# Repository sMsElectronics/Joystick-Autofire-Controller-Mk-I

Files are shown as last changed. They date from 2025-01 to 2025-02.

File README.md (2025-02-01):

# Joystick Auto Fire Controller V1.1
 ### This is a small form factor digitally controlled auto fire PCB with 0.1" connector headers for convenient installation into Commodore 64 and Atari Joysticks. It can be used to create custom DIY joysticks. Fire rates can be controlled using a potentiometer (analog mode) to smoothly transition from fire rate from 2 to 25 pulses per second (PPS). Alternatively, you can enter a fixed rates mode (digital Mode) with a series of button presses. The fixed rate selections are 5, 10, and 15 PPS. A normal mode is also possible by disabling the auto fire in both scenarios above. All feedback is displayed on an RGB WS2812B compatible LED and FIRE LED. Various colors and fade animation are displayed representing all the modes and rates. Further below, these modes and how to enter them are described in the illustrations

 ## *The complete and tested auto fire controller PCB's, complete with documentation, are available on my sMs Retro Electronics KoFi Shop*

## [sMs Retro Electronics KoFi Shop](https://ko-fi.com/smsretroelectronics)

 ## Size of board compared to the end of a pen.  

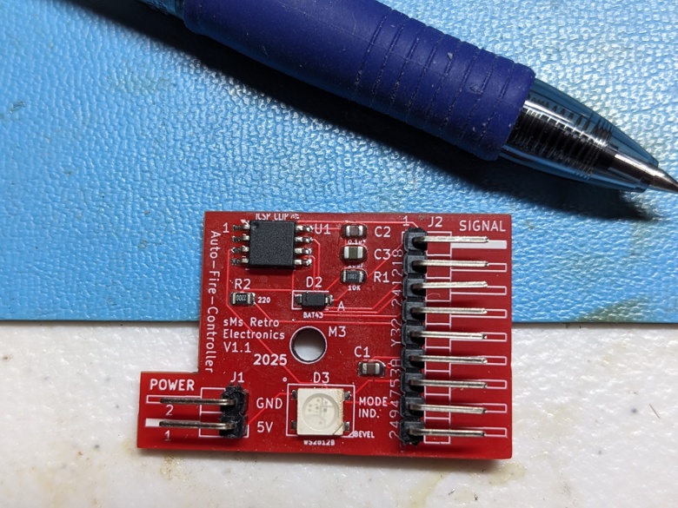
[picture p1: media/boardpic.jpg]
 

 ## PCB TOP VIEW
 
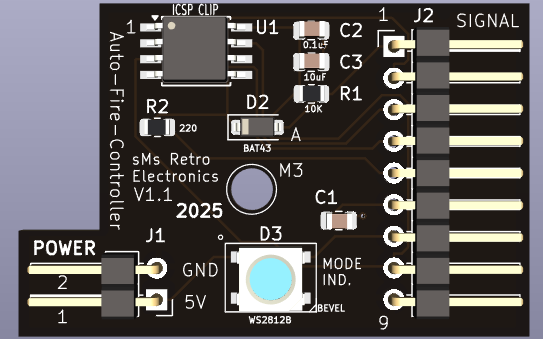
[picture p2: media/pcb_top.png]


 ## PCB BOTTOM VIEW
### A convenient silkscreen showing signal names NOTE: SQUARE PIN = 1

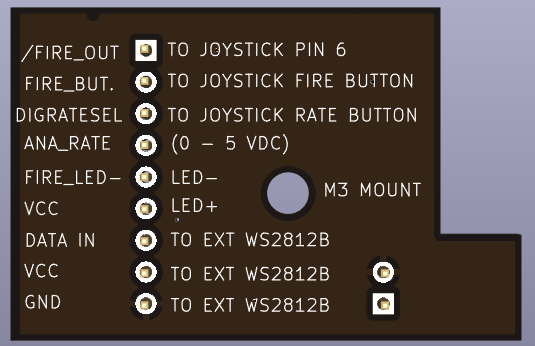
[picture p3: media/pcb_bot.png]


# J2 Signal Definitions: 

|Pin Number|Signal Name|Description|
|:--:|:--:|:--|
|1|/FIRE OUT|Active low signal output that emulates the trigger into the C64 or other computer to auto fire a weapon. This signal is normally HIGH. Signal wires to pin 6 of a joystick: 
|2|FIRE_BUT|Signal from fire control button on joystick. This signal pulls LOW each time the joystick fire button is pressed. This signal is normally HIGH. :
|3|DIGRATESEL|Selects the auto fire rate. Rates of 5, 10 and 20 PPS are selectable. A Quick press cycles theSE rates. A long press FOR 1.5+ seconds enables the analog rate control| 
|4|ANA_RATE|A 0-5 VDC input from external 10K potentiometer to vary the fire rate from 2 to 23 pulses per second. This potentiometer input is only active if the joystick is set to smooth analog fire control|
|5|Fire LED-|output for user option to mount external led to indicate the press of the fire button in normal mode or to indicate auto fire pulsing in either of two auto fire modes|
|6|VCC|supply for LED+. No limiting resistor is required|
|7|DATA IN|External Neopixel RGB LED Data IN Signal|
|8|VCC|5V supply for Neopixel|
|9|GND|Ground connection for Neopixel|

# J1 Signal Definitions: 

|Pin Number|Signal Name|
|:--:|:--|
|1|5V IN|
|2|GROUND| 
   
# Summary of Modes

- Fixed Auto fire Mode
- Smooth or Analog Fire 
- Normal Mode
  
# How to Enter and Operate Each Mode

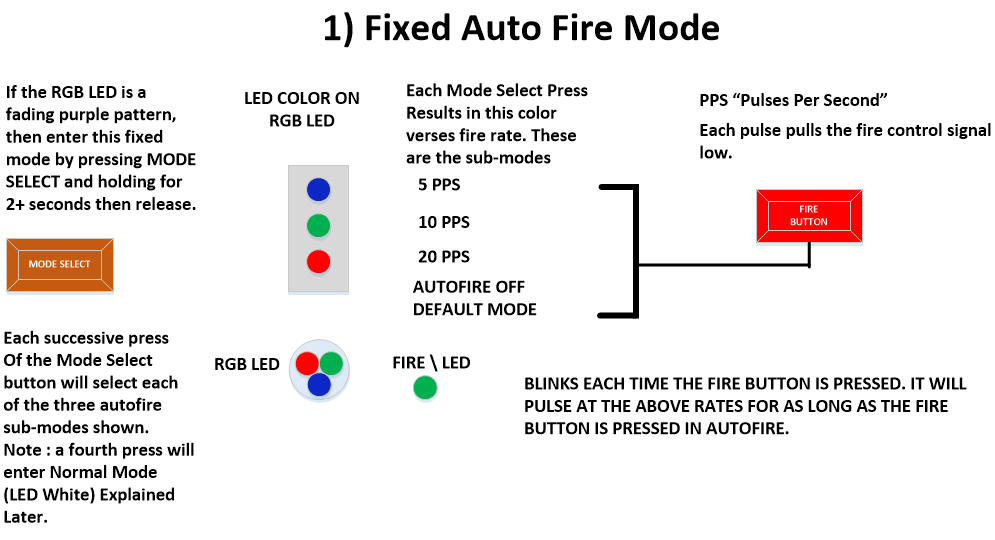
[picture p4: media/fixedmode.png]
 
 <BR>

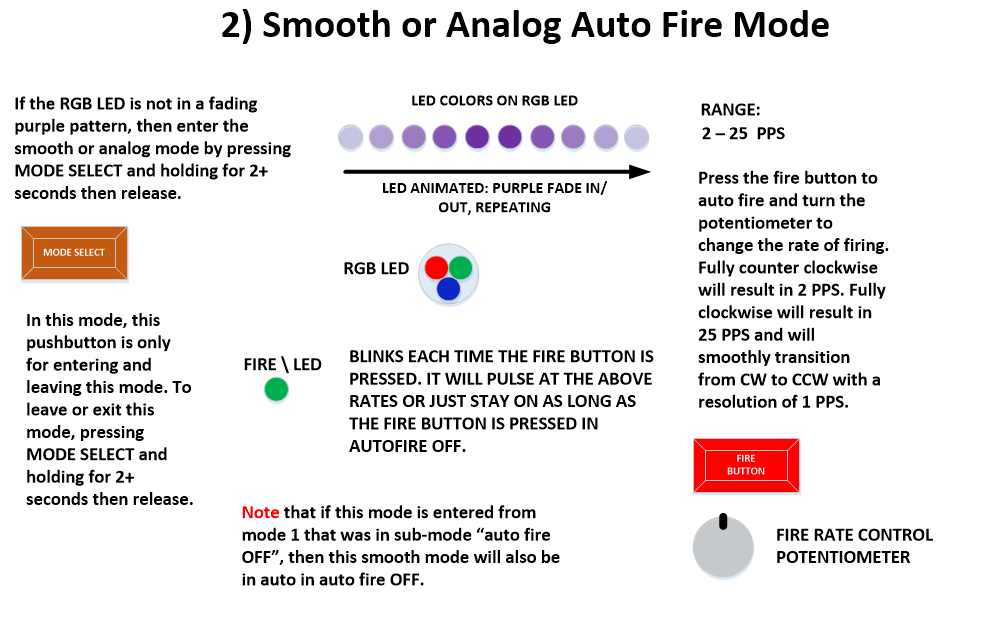
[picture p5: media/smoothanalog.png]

<BR>

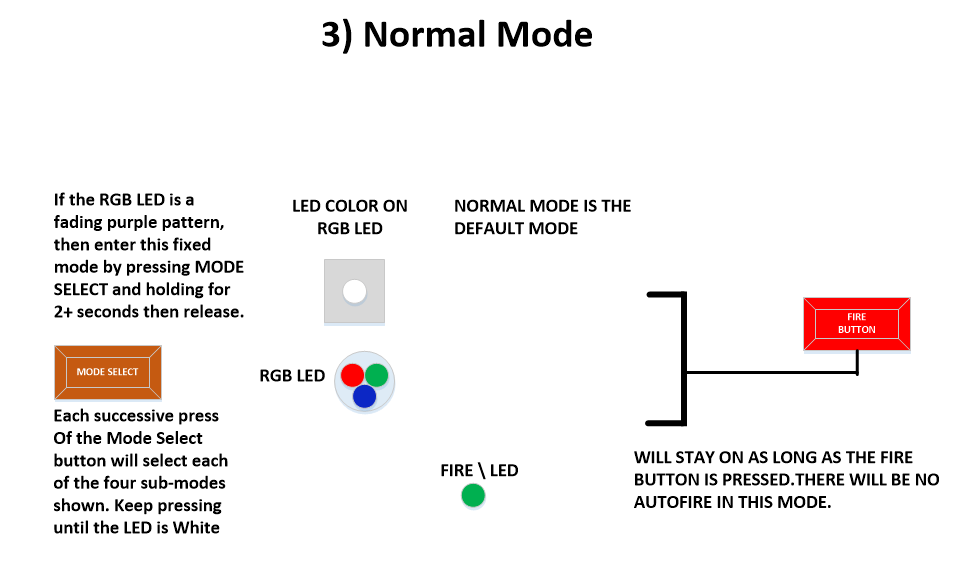
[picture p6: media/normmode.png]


# Typical application in a joystick design

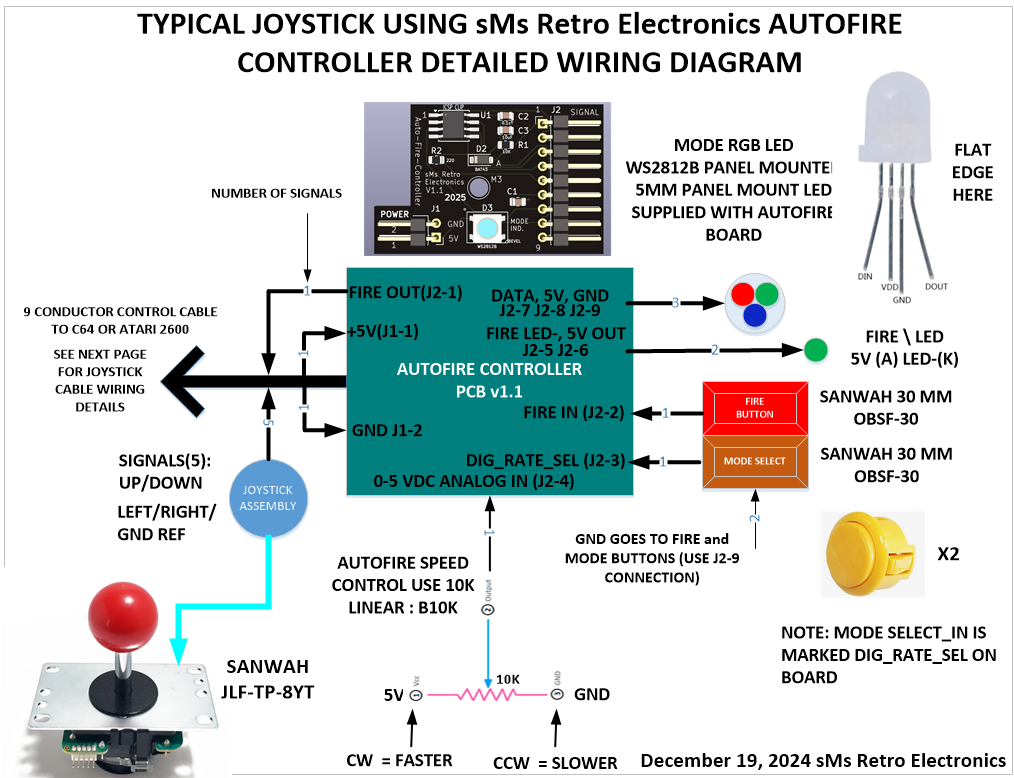
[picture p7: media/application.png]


# Joystick wiring details

The following diagram shows how to wire a Sanwah JLF-TP-8YT joystick , or compatible, assembly to a 9 PIN joystick cable. Some cables may be different in their color coding so its best to check continuity from each pin to the wires and identify the color verses pin. 

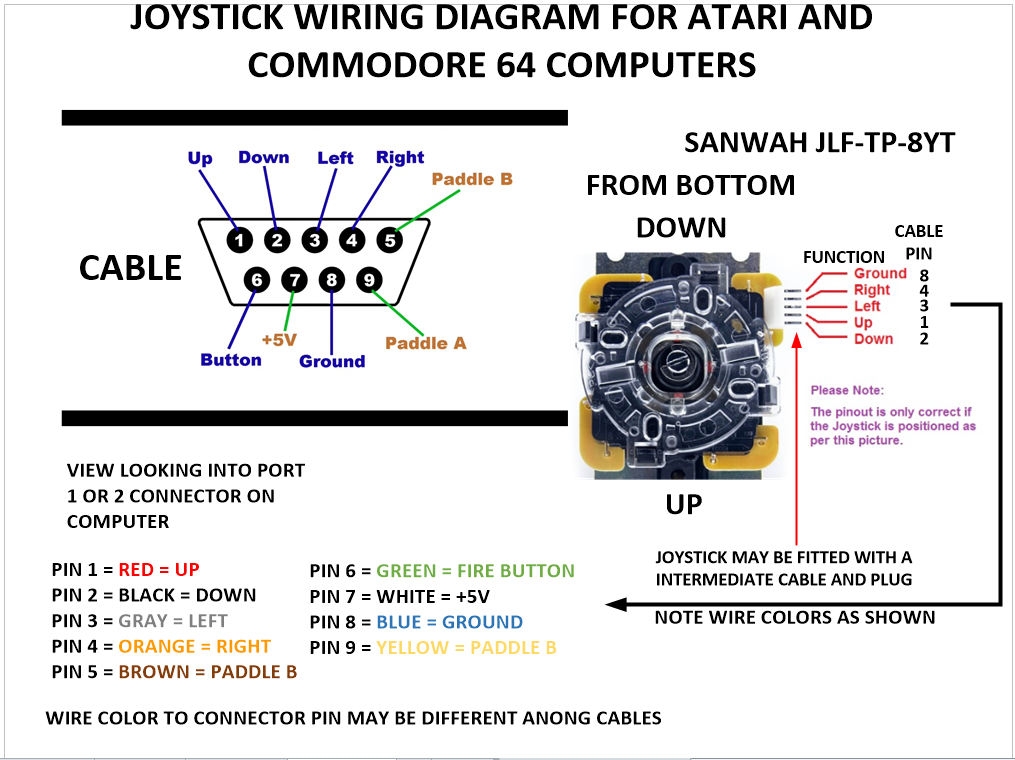
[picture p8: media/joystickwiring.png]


## If you want to DIY build your boards, the source files are available in the VS Code folder. Just keep in mind that when you create the project, inside the "libdeps" folder that contains the Tinbutton folder and TinyButton.cpp file. This file has been modifed to work with this project with the following changes. It was found that a long button press of 4 seconds was way too long and the long press woul dbe activated in 1.5 seconds instead.    

   ## Modification to file ***TinyButton.cpp*** to Shorten the LONG press criteria from 4 seconds to 1.5 seconds 
   ### W.Manganaro 2025
   
## FROM:    

      if ((currentMillis - _buttonPressTime) >= 4000)  
## TO:    

      //Value changed from 4000 to 1500 to validate a LONG press in a shorter time (approx 1.5 seconds)
      if ((currentMillis - _buttonPressTime) >= 1500)

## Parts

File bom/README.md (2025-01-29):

| Reference | Value | Footprint | Qty |
|---|---|---|-----|
| C1,C2,C3  | 0.1uF_0805_16V | Capacitor_SMD:C_0805_2012Metric | 3 |
| D2 | BAT43 | Diode_SMD:D_SOD-123 | 1 |
| D3 | WS2812B | LED_SMD:LED_WS2812B_PLCC4_5.0x5.0mm_P3.2mm | 1 |
| J1 | Conn_01x02 | Connector_PinHeader_2.54mm:PinHeader_1x02_P2.54mm_Horizontal | 1 |
| J2 | Conn_01x09 | Connector_PinHeader_2.54mm:PinHeader_1x09_P2.54mm_Horizontal | 1 |
| R1 | 10k_0805 | Resistor_SMD:R_0805_2012Metric | 1 |
| R2 | 220_0805 | Resistor_SMD:R_0805_2012Metric | 1 |
| U1 | ATtiny85V-10SU | Package_SO:SOIC-8W_5.3x5.3mm_P1.27mm | 1 |

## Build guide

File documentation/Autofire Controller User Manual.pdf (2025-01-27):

# AUTOFIRE CONTROLLER ASSEMBLY

# TOP

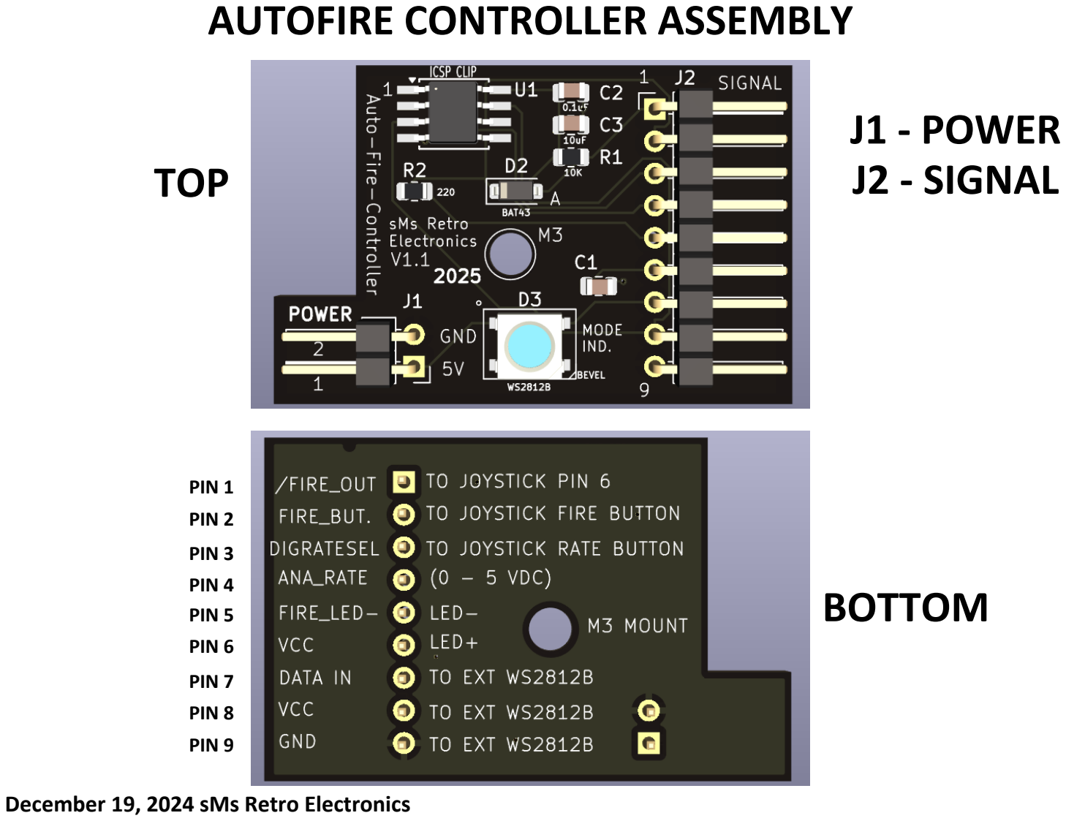
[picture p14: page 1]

# BOTTOM

# J1 - POWER J2 - SIGNAL

PIN 1
PIN 2
PIN 3
PIN 4
PIN 5
PIN 6
PIN 7
PIN 8
PIN 9

December 19, 2024 sMs Retro Electronics

# AUTOFIRE CONTROLLER SCHEMATIC DIAGRAM

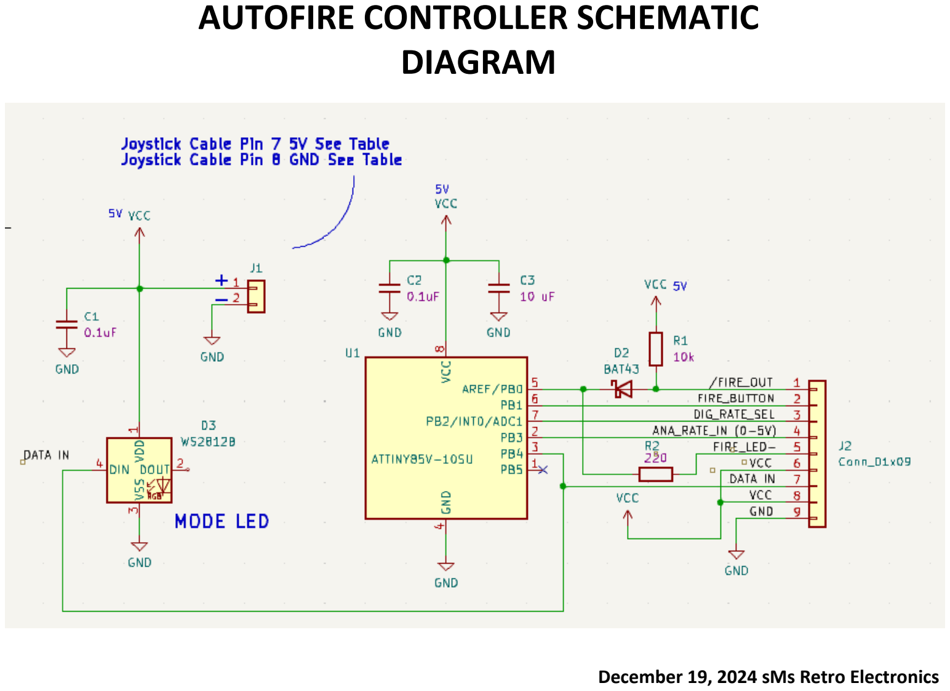
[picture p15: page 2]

# AUTOFIRE CONTROLLER SIGNAL DESCRIPTIONS

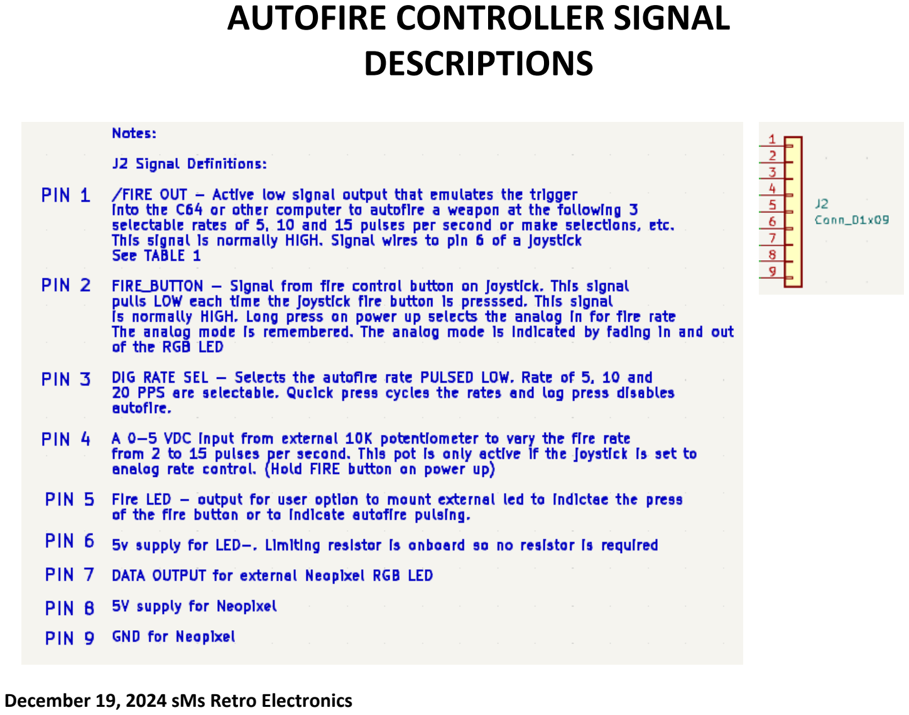
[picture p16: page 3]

### Three Modes of Operation. (Modes 1 & 2 Press and Hold Fire Button) 1) Fixed Auto Fire

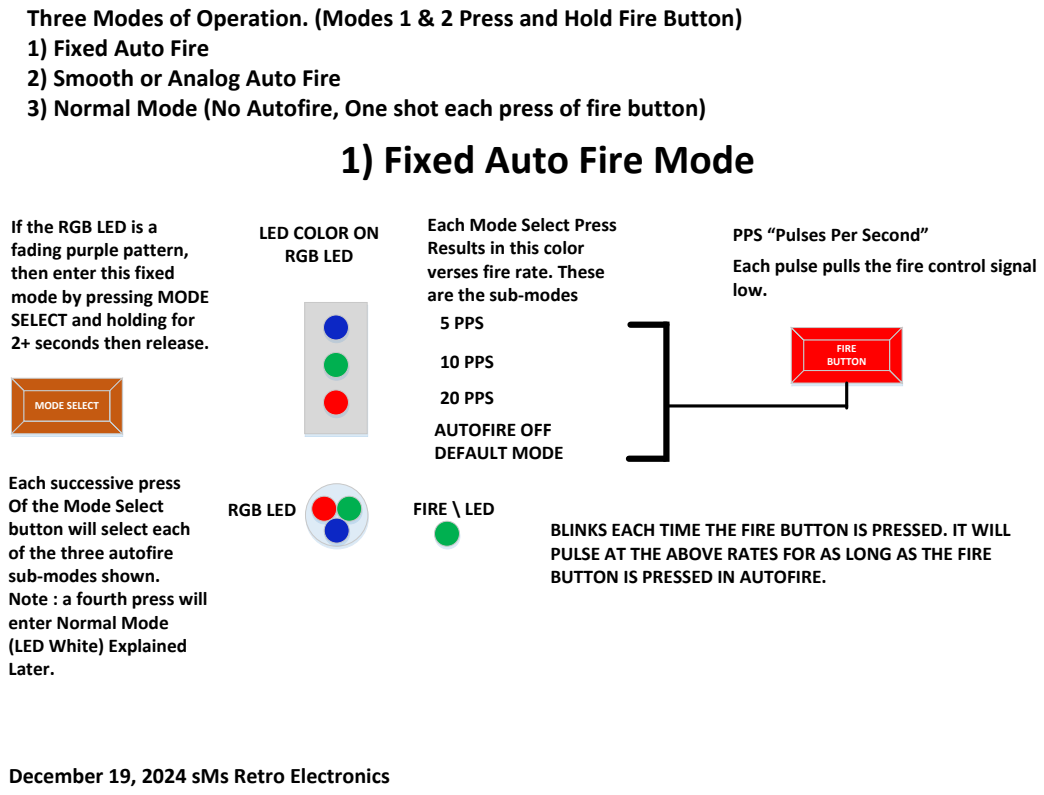
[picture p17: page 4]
10 PPS; 20 PPS; AUTOFIRE OFF DEFAULT MODE; low.; Button FIRE BUTTON; MOBDuEtStoEnLECT; RGB LED

2) Smooth or Analog Auto Fire
3) Normal Mode (No Autofire, One shot each press of fire button)

1) Fixed Auto Fire Mode

If the RGB LED is a
fading purple pattern, then enter this fixed

LED COLOR ON
RGB LED

Each Mode Select Press
Results in this color
verses fire rate. These
are the sub-modes
5 PPS

PPS “Pulses Per Second” Each pulse pulls the fire control signal

mode by pressing MODE
SELECT and holding for
2+ seconds then release.

Each successive press
Of the Mode Select
button will select each
of the three autofire
sub-modes shown. Note : a fourth press will

BUTTON IS PRESSED IN AUTOFIRE. FIRE \ LED

BLINKS EACH TIME THE FIRE BUTTON IS PRESSED. IT WILL
PULSE AT THE ABOVE RATES FOR AS LONG AS THE FIRE

enter Normal Mode
(LED White) Explained
Later.

FIRE RATE CONTROL
POTENTIOMETER

2 – 25 PPS

RANGE:

# 2) Smooth or Analog Auto Fire Mode

BLINKS EACH TIME THE FIRE BUTTON IS PRESSED. IT WILL PULSE AT THE ABOVE RATES OR JUST STAY ON AS LONG AS THE FIRE BUTTON IS PRESSED IN

AUTOFIRE OFF. FIRE \ LED

In this mode, this
pushbutton is only
for entering and
leaving this mode. To
leave or exit this
mode, pressing
MODE SELECT and
holding for 2+
seconds then release.

MOBDuEtStoEnLECT

If the RGB LED is not in a fading purple pattern, then enter the
smooth or analog mode by pressing
MODE SELECT and holding for 2+
seconds then release. | RGB LED

Button FIRE
BUTTON

Press the fire button to
auto fire and turn the
potentiometer to
change the rate of firing. Fully counter clockwise

will result in 2 PPS. Fully clockwise will result in

### 25 PPS and will

smoothly transition
from CW to CCW with a
resolution of 1 PPS.

LED COLORS ON RGB LED

LED ANIMATED: PURPLE FADE IN/ OUT, REPEATING

Note that if this mode is entered from mode 1 that was in sub-mode “auto fire OFF”, then this smooth mode will also be in auto in auto fire OFF.

# 3) Normal Mode

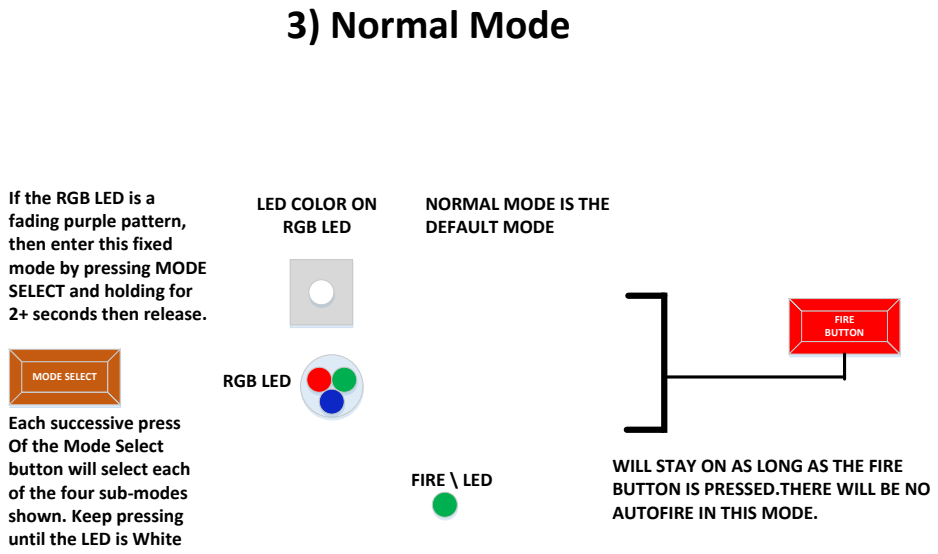
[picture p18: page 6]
Button FIRE BUTTON; MOBDuEtStoEnLECT; RGB LED

If the RGB LED is a
fading purple pattern, then enter this fixed

LED COLOR ON
RGB LED

NORMAL MODE IS THE
DEFAULT MODE

mode by pressing MODE
SELECT and holding for
2+ seconds then release.

Each successive press
Of the Mode Select
button will select each
of the four sub-modes
shown. Keep pressing
until the LED is White

WILL STAY ON AS LONG AS THE FIRE
BUTTON IS PRESSED.THERE WILL BE NO

AUTOFIRE IN THIS MODE. FIRE \ LED

# TYPICAL JOYSTICK USING sMs Retro Electronics AUTOFIRE CONTROLLER DETAILED WIRING DIAGRAM

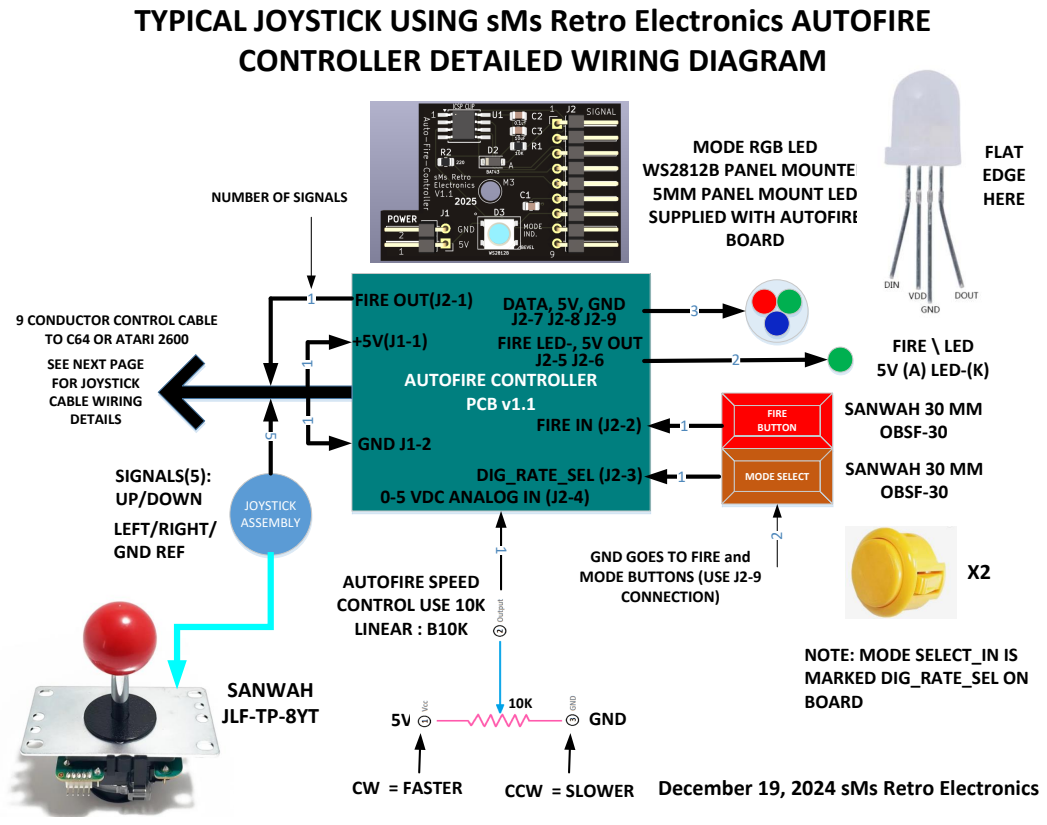
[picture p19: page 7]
AUTOFIRE CONTROLLER PCB v1.1; Button FIRE BUTTON; MOBDuEtStoEnLECT; BOARD; FIRE \ LED 5V (A) LED-(K); FIRE OUT(J2-1); SIGNALS(5): UP/DOWN; LEFT/RIGHT/ GND REF; FIRE IN (J2-2); DIG_RATE_SEL (J2-3); FIRE LED-, 5V OUT; JOYSTICK ASSEMBLY; +5V(J1-1) GND J1-2 ¹ ¹; DATA, 5V, GND; SANWAH 30 MM OBSF-30; FLAT EDGE HERE; AUTOFIRE SPEED CONTROL USE 10K LINEAR : B10K; GND; SANWAH JLF-TP-8YT; CW = FASTER; CCW = SLOWER

MODE RGB LED
WS2812B PANEL MOUNTED
5MM PANEL MOUNT LED
SUPPLIED WITH AUTOFIRE

NUMBER OF SIGNALS

9 CONDUCTOR CONTROL CABLE
TO C64 OR ATARI 2600
SEE NEXT PAGE
FOR JOYSTICK
CABLE WIRING
DETAILS

0-5 VDC ANALOG IN (J2-4)

GND GOES TO FIRE and
MODE BUTTONS (USE J2-9
CONNECTION)

NOTE: MODE SELECT_IN IS
MARKED DIG_RATE_SEL ON
BOARD

# JOYSTICK WIRING DIAGRAM FOR ATARI AND COMMODORE 64 COMPUTERS

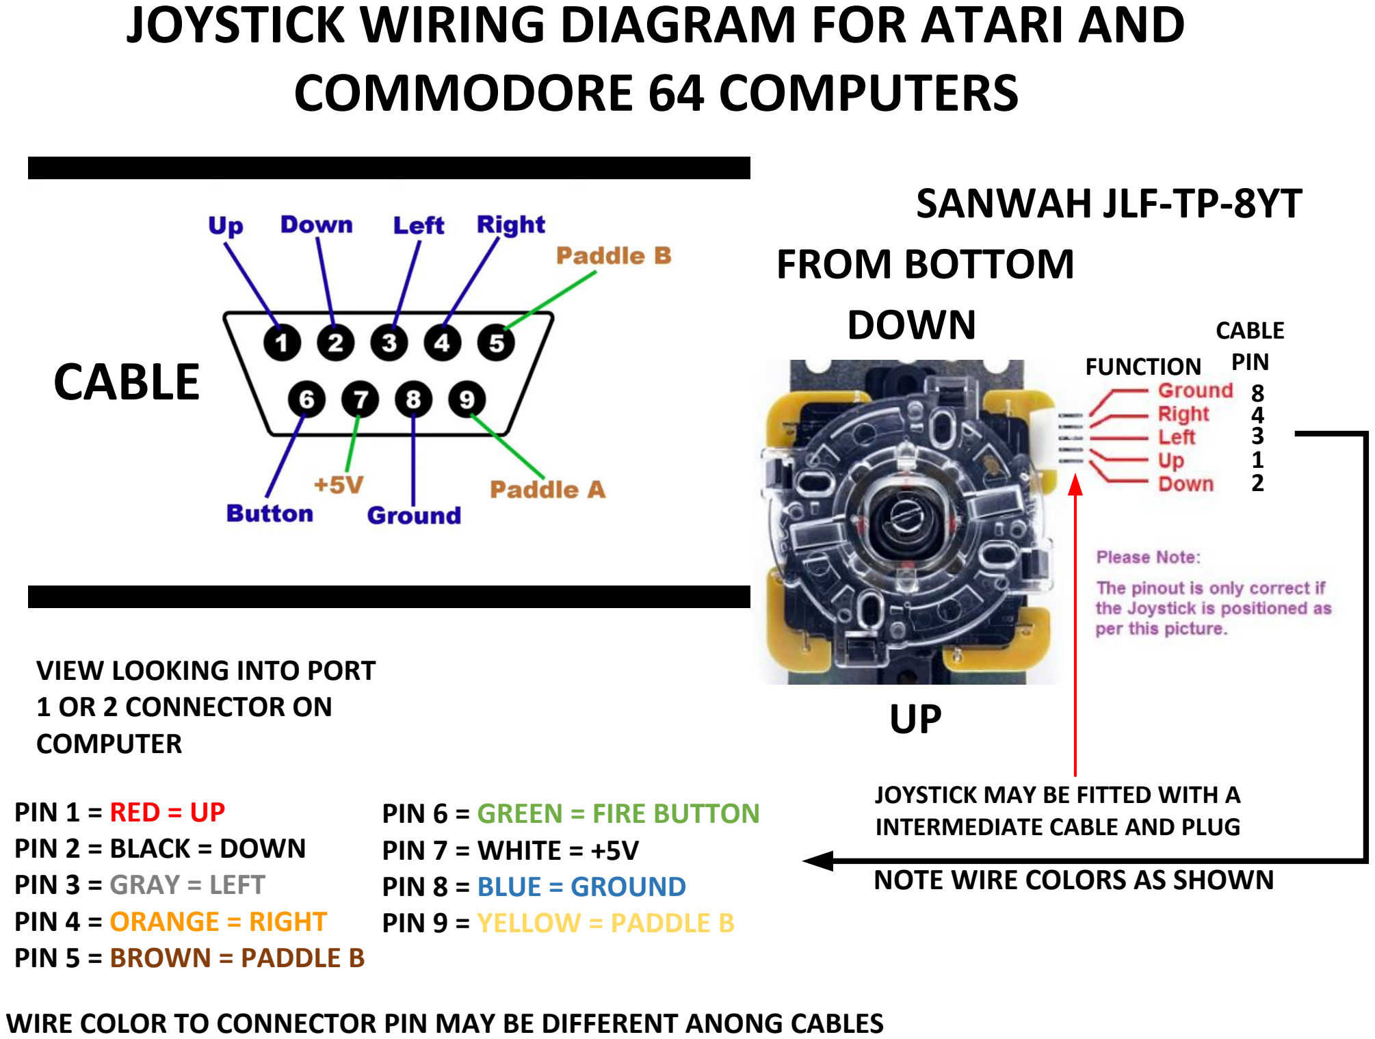
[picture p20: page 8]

VIEW LOOKING INTO PORT

### 1 OR 2 CONNECTOR ON

COMPUTER

PIN 1 = RED = UP
PIN 2 = BLACK = DOWN
PIN 3 = GRAY = LEFT
PIN 4 = ORANGE = RIGHT
PIN 5 = BROWN = PADDLE B

PIN 6 = GREEN = FIRE BUTTON PIN 7 = WHITE = +5V
PIN 8 = BLUE = GROUND
PIN 9 = YELLOW = PADDLE B

WIRE COLOR TO CONNECTOR PIN MAY BE DIFFERENT ANONG CABLES

UP

# DOWN

8
4
3
1
2

CABLE
FUNCTION PIN

JOYSTICK MAY BE FITTED WITH A INTERMEDIATE CABLE AND PLUG

# SANWAH JLF-TP-8YT

# CABLE

# FROM BOTTOM

NOTE WIRE COLORS AS SHOWN

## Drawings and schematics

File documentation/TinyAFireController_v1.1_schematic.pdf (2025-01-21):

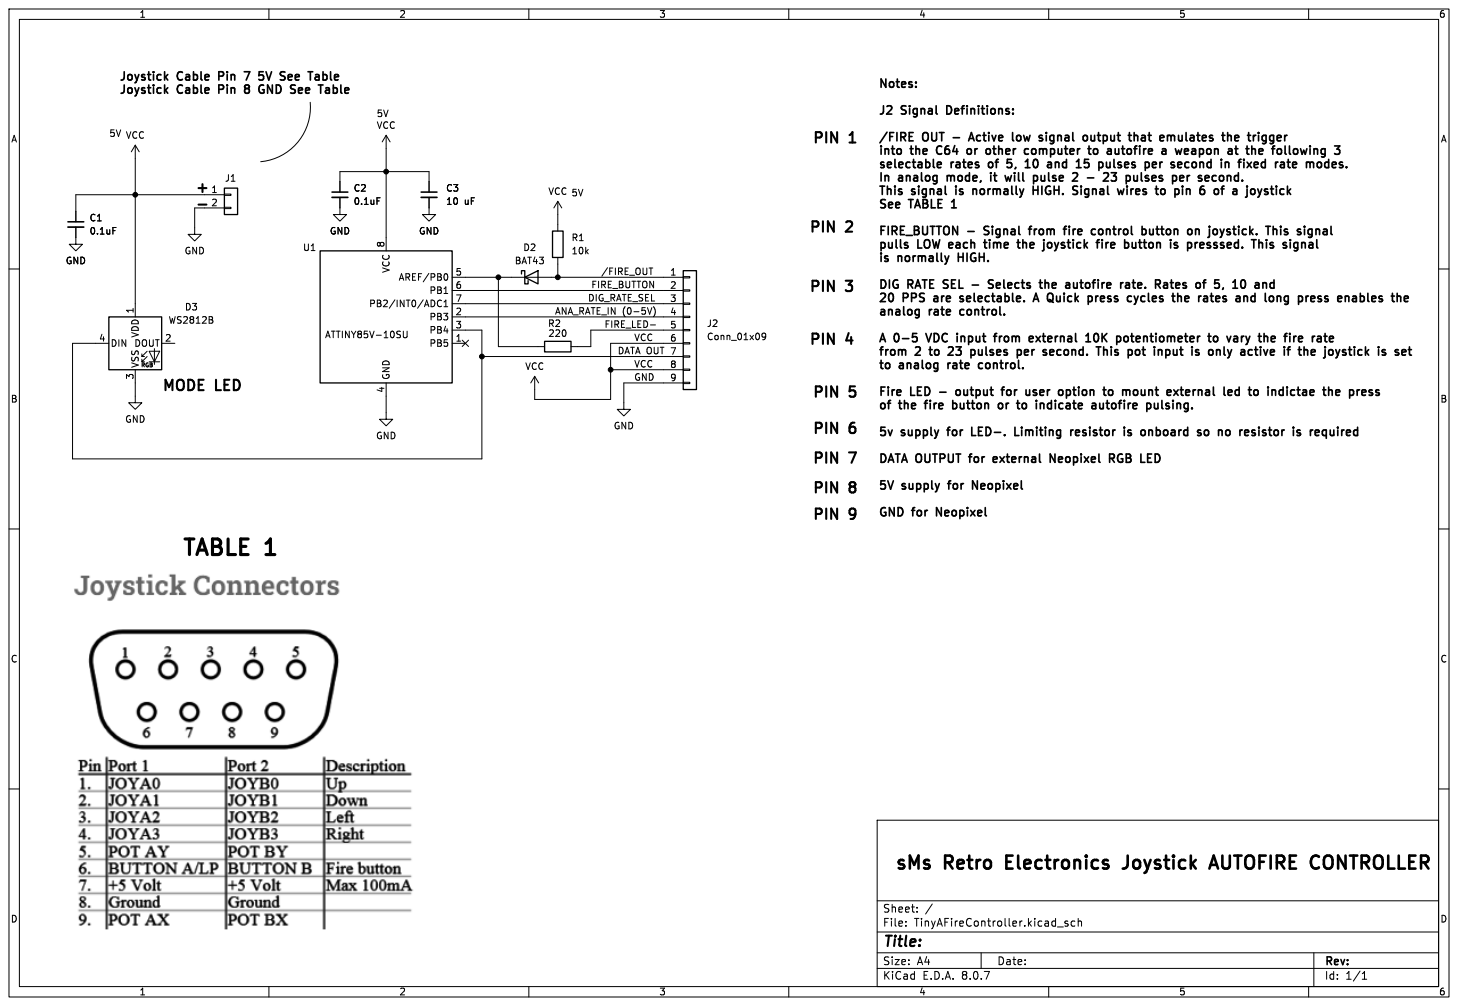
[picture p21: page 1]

Joystick Cable Pin 7 5V See Table
5VJoystick Cable Pin 8 GND See Table

See TABLE 1 FIRE_BUTTON - Signal from fire control button on joystick. This signal

pulls LOW each time the joystick fire button is presssed. This signal
is normally HIGH.

DIG RATE SEL - Selects the autofire rate. Rates of 5, 10 and
analog rate control.

from 2 to 23 pulses per second. This pot input is only active if the joystick is set
to analog rate control.

Fire LED - output for user option to mount external led to indictae the press
of the fire button or to indicate autofire pulsing.

5v supply for LED-. Limiting resistor is onboard so no resistor is required

DATA OUTPUT for external Neopixel RGB LED

Id: 1/1 Title: File: TinyAFireController.kicad_sch Sheet: /

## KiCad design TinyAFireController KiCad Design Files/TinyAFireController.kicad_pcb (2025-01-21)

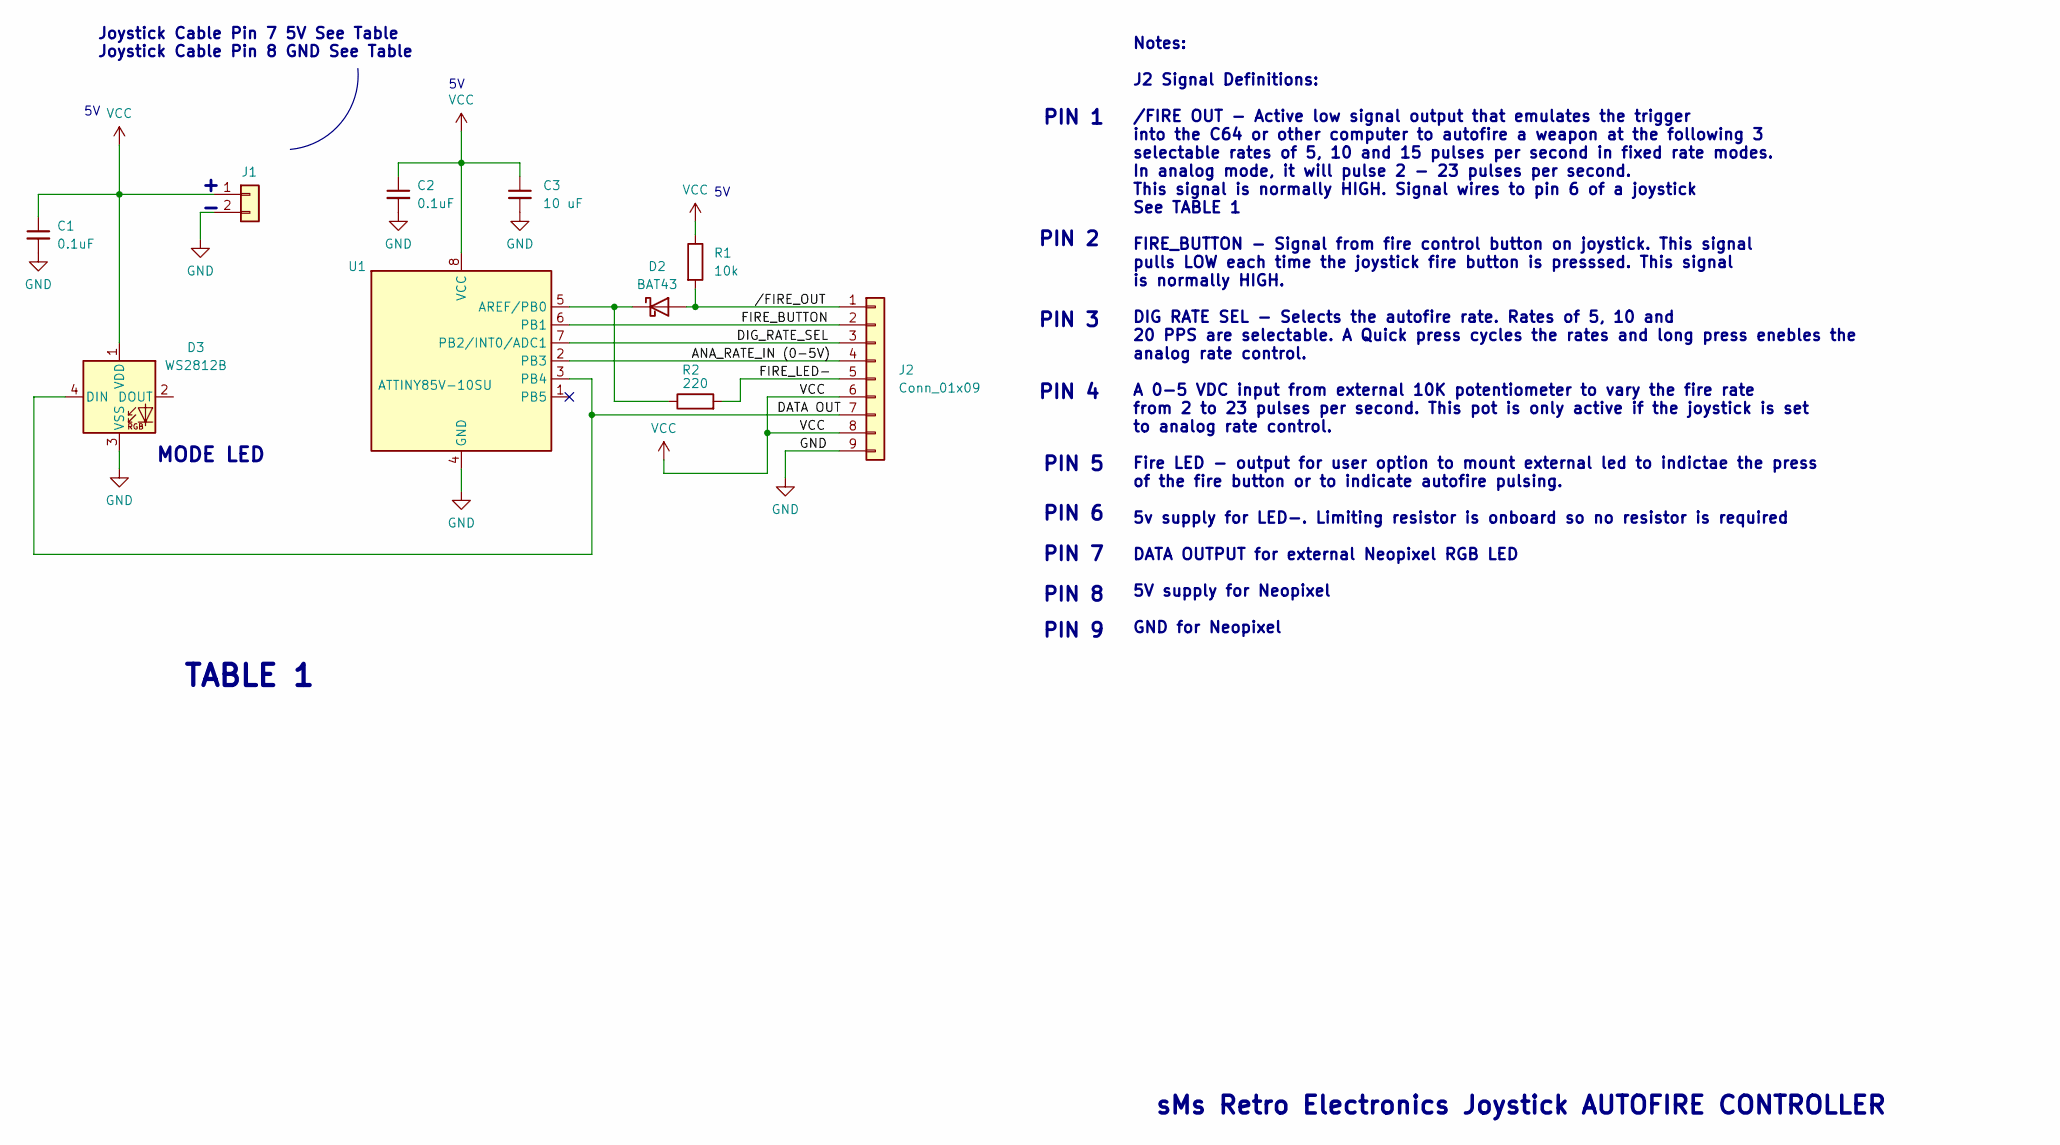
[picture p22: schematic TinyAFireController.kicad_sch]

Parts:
C1, C2, C3: 0.1uF_0603_16V; C_0805_2012Metric; Part Number 0603YC104KAT2A; JLCPCB ID C14663
D2: BAT43; D_SOD-123
D3: WS2812B; LED_WS2812B_PLCC4_5.0x5.0mm_P3.2mm
J1: Conn_01x02; PinHeader_1x02_P2.54mm_Horizontal; Part Number 1-0201FBV0T
J2: Conn_01x09; PinHeader_1x09_P2.54mm_Horizontal; Part Number 1-0901FBV0T
R1, R2: 100k_0603; R_0805_2012Metric; Part Number RC0603FR-07100KL; JLCPCB ID C25803
U1: ATTINY85V-10SU; SOIC-8W_5.3x5.3mm_P1.27mm

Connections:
/: D2.1 (K), R2.1, U1.5 (AREF/PB0)
/ANA_RATE_IN (0-5V): J2.4, U1.2 (PB3)
/DATA IN: D3.4 (DIN), J2.7, U1.3 (PB4)
/DIG_RATE_SEL: J2.3, U1.7 (PB2/INT0/ADC1)
/FIRE_BUTTON: J2.2, U1.6 (PB1)
/FIRE_LED-: J2.5, R2.2
//FIRE_OUT: D2.2 (A), J2.1, R1.2
GND: C1.2, C2.2, C3.2, D3.3 (VSS), J1.2, J2.9, U1.4 (GND)
VCC: C1.1, C2.1, C3.1, D3.1 (VDD), J1.1, J2.6, J2.8, R1.1, U1.8 (VCC)

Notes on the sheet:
TABLE 1
PIN 5
Joystick Cable Pin 7 5V See Table
PIN 7
PIN 1
PIN 3
PIN 6
sMs Retro Electronics Joystick AUTOFIRE CONTROLLER
MODE LED
PIN 8
Notes: J2 Signal Definitions: /FIRE OUT - Active low signal output that emulates the trigger into the C64 or other computer to autofire a weapon at the following 3 selectable rates of 5, 10 and 15 pulses per second in fixed rate modes. In analog mode, it will pulse 2 - 23 pulses per second. This si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
Joystick Cable Pin 8 GND See Table
PIN 4
PIN 2
PIN 9

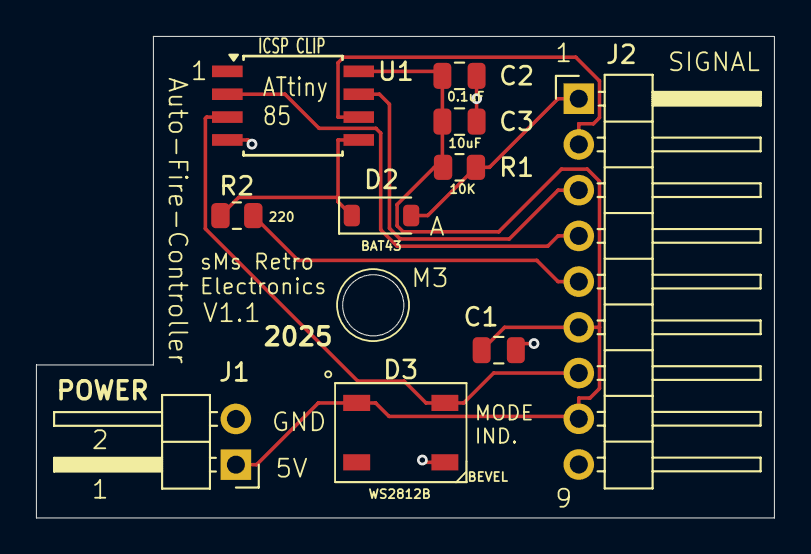
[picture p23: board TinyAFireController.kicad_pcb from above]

Board: 2 copper layers, 41.0 x 26.8 mm, 10 parts (0 on the bottom side), 9 nets.

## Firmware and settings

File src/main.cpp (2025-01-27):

/*  ; MIT License
; 
; Copyright (c) 2025 William Manganaro sMs Retro Electronics
; 
; Permission is hereby granted, free of charge, to any person obtaining a copy of this software 
; and associated documentation files (the "Software"), to deal in the Software without 
; restriction, including without limitation the rights to use, copy, modify, merge, publish, 
; distribute, sublicense, and/or sell copies of the Software, and to permit persons to whom 
; the Software is furnished to do so, subject to the following conditions:
; 
; The above copyright notice and this permission notice shall be included in all copies or 
; substantial portions of the Software.
; 
; THE SOFTWARE IS PROVIDED "AS IS", WITHOUT WARRANTY OF ANY KIND, EXPRESS OR IMPLIED, INCLUDING 
; BUT NOT LIMITED TO THE WARRANTIES OF MERCHANTABILITY, FITNESS FOR A PARTICULAR PURPOSE AND 
; NONINFRINGEMENT. IN NO EVENT SHALL THE AUTHORS OR COPYRIGHT HOLDERS BE LIABLE FOR ANY CLAIM, 
; DAMAGES OR OTHER LIABILITY, WHETHER IN AN ACTION OF CONTRACT, TORT OR OTHERWISE, ARISING FROM, 
; OUT OF OR IN CONNECTION WITH THE SOFTWARE OR THE USE OR OTHER DEALINGS IN THE SOFTWARE.
*/

#include <Arduino.h>
#include <TinyButton.h>
#include <FastLED.h>

// pin defines
#define DIG_RATE_SEL 2
#define FIRE_OUT 0
#define FIRE_BUTTON 1
#define DATA_PIN 4
#define LED_TYPE    WS2812
#define COLOR_ORDER RGB
#define NUM_LEDS    1
#define BRIGHTNESS  128 // default brightness
CRGB leds[NUM_LEDS];

// variables
bool analog_rate_flag = false; // if this is false, then fixed rate controls are used
bool autofire_enable_flag = true; // when flag is true, autofire is enabled.
bool was_in_analog_mode = false; // this tells the process that the joystick was in analog more and needs the leds to revert back to original color
int ana_rate_in = A3;   // select the input pin for the potentiometer
int rateValue; // analog autofire rate value scaled from 2 to 25 pulses per second
int fixed_delay; // represents the delay used if in autorate and fixed modes 5-10-20 PPS 
byte fade_loop_divider = 4;  
byte brightness_level = 0;
signed int n=1; 
byte mode_counter = 3; // mode counter will span 0-3 that represent three spped variables and disable. 
// init the fire rate to the lowest to 5 pulse per second
// 0 = 5 pps 1 = 10 pps 2 = 15 pps 3 = disabled, no autofire
int delay_val[] = {250,167,125,100,84,72,63,56,50,46,42,39,36,33,31,29,27,26,25,24,23,22,21,20}; // pps = 1/(2*delay_val(n)) where n= eleement of array in milliseconds

// object definitions
TinyButton myButton(DIG_RATE_SEL); // create the object myButton on port b.2 and name the button myButton

// functions


void set_led_color () 

{
  FastLED.setBrightness(128);
  if (mode_counter==0 ) {leds[0] = CRGB::Blue; //glow 1st led as blue, the slowest auto fire rate
    FastLED.show(); 
    fixed_delay=100;}// apply the function on led strip}
    if (mode_counter==1 ) {leds[0] = CRGB::Green; //glow 1st led as green, the slowest auto fire rate
    FastLED.show();
    fixed_delay=50; }// apply the function on led strip}
    if (mode_counter==2 ) {leds[0] = CRGB::Red; //glow 1st led as red, the slowest auto fire rate
    FastLED.show();
    fixed_delay=25; }// apply the function on led strip}
    if (mode_counter==3 ) {leds[0] = CRGB::White; //glow 1st led as white, the slowest auto fire rate
    FastLED.show(); }// apply the function on led strip}}
}

// read a/d potentiometer and scale the rate to 2 - 20 pps
void read_potentiometer() {
    rateValue = map(analogRead(ana_rate_in), 0, 1023, 0, 23); // scale a/d value to a range of autorate vales from 0-1023 to 2-20 PPS
    
}
// Function that is triggered by a normal click
void mode_change_fixed_rates()
{           
            mode_counter++;
            set_led_color();
            if (mode_counter>3) {
              mode_counter=0;
            set_led_color();
              }
}


// Function that is triggered by a long click
// if this flag is TRUE, then rate control is input from the analog input 
// if the flag is FALSE then the control is handed to the DIG_RATE_SEL input
void analog_rate_control_enable()
{
        analog_rate_flag = !analog_rate_flag; // toggle the flag
        if (analog_rate_flag== false && was_in_analog_mode == true) {
            set_led_color();
                }
}


void setup() {
    pinMode(5,OUTPUT); // port b pin 5 is not used but is still prudent o define a state
    digitalWrite(5, HIGH); // init the portb.5 output to logic high
    pinMode(FIRE_OUT, OUTPUT); // define the fire output signal (active low)
    digitalWrite(FIRE_OUT, HIGH); // init the fire output signal to logic high
    pinMode(FIRE_BUTTON, INPUT); // fire button input 
    pinMode(DIG_RATE_SEL, INPUT); // digital rate select input 
    PORTB |= (1 << PB1 | 1 << PB2);  //activate pull-up resistor for PB1 & PB2 inputs
    ADCSRA|= (1 << ADPS0 | 1 << ADPS2); // A/D clk div 32 125 ksps conversion time = 102 uS 
    myButton.attachClick(mode_change_fixed_rates); // This is the function for the normal click
    myButton.attachLongClick(analog_rate_control_enable);   // This is the function for the long click
    FastLED.addLeds<LED_TYPE,DATA_PIN,COLOR_ORDER>(leds, NUM_LEDS);
    FastLED.setBrightness(BRIGHTNESS);
    leds[0] = CRGB::White; //glow 1st led as white, no autofire enabled
    FastLED.show(); // apply the function on led strip
}


void loop() {
 myButton.tick();
 while (digitalRead(FIRE_BUTTON)==0)
 {
  if (autofire_enable_flag==true && analog_rate_flag == false && mode_counter<3) // are we in auto fire mode and not in analog mode, then strobe the fire scontrol signal at fixed rate
  {
   digitalWrite(FIRE_OUT, LOW); // fire
   delay(fixed_delay);
   digitalWrite(FIRE_OUT, HIGH); // release
   delay(fixed_delay);
  }
  else 
  { digitalWrite(FIRE_OUT, LOW);  } // fire control ignal ust follows the fire button

if (autofire_enable_flag==true && analog_rate_flag == true && mode_counter<3) // are we in auto fire mode and not in analog mode, then strobe the fire scontrol signal at fixed rate
  {
   read_potentiometer();
   digitalWrite(FIRE_OUT, LOW); // fire
   delay(delay_val[rateValue]);
   digitalWrite(FIRE_OUT, HIGH); // release
   delay(delay_val [rateValue]);
  }
  else 
  { digitalWrite(FIRE_OUT, LOW);  } // fire control ignal ust follows the fire button

     }
   digitalWrite(FIRE_OUT, HIGH); // place fire control signal in inactive state

//   while (analog_rate_flag == true && loop_count==0)
   if (analog_rate_flag == true)
   {
     was_in_analog_mode= true;
     FastLED.setBrightness(brightness_level);
     leds[0] = CRGB::Purple; //glow 1st led as white, no autofire enabled
     FastLED.show(); // apply the color to led
     fade_loop_divider++;
     if (fade_loop_divider==3){
           brightness_level+=n;
     if (brightness_level==200) {n*=-1;}
     if (brightness_level==0) {n*=-1;}
     fade_loop_divider=0;
     }
      }


   }

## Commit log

2024-12-29 First Commit
    Added the Kicad Design Files
    [TinyAFireController.kicad_pcb, TinyAFireController.kicad_sch]
2025-01-21 Added to Kicad
    SCH PDF and Gerber V1.1
    [TinyAFireController.kicad_pcb]
2025-01-27 Numerious changes for first publish
    added many files to repository and created readme.md file.
    [TinyAFireController-B_Cu.gbr, TinyAFireController-B_Mask.gbr, TinyAFireController-B_Paste.gbr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]
2025-01-29 Added BOM
    Created a BOM.md file
    Corrected wrong resistor values for R1 and R2
    [TinyAFireController.csv, TinyAFireController.xlsx]
2025-01-29 Create README.md
    Changed the name from BOM.md to README.md so that the BOM appears as a table automatically.
2025-01-29 Deleted BOM.md
    Deleted file because it is not required
2025-02-01 Update README.md
    Added notes on what needs to be modified in the TinyButton library in order for the long button press to work within a reasonable time.
